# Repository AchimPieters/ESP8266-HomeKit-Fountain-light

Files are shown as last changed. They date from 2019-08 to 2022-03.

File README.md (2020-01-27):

# ESP8266-HomeKit-Fountain-light
ESP8266 – HomeKit Fountain light

For More Information Visit http://www.studiopieters.nl/

- [x] Make a new NeoPixel Ring
- [x] Beta Testing Software
- [x] Make A PCB
- [x] Ordering PCB Parts
- [x] Beta Testing PCB
- [x] Hardware Installation
- [x] Make POC Movie
- [x] Make end result Movie
- [x] Release KiCad files
- [x] Release gerber files

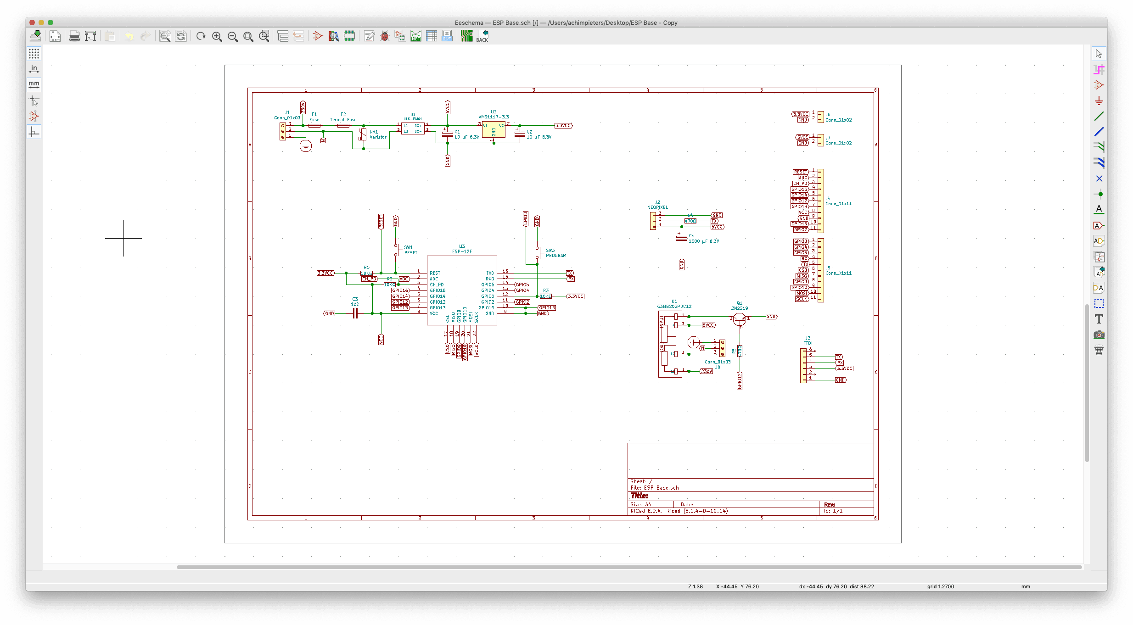
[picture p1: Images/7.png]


 




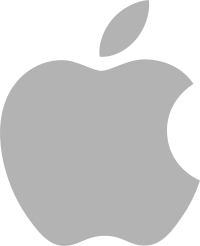
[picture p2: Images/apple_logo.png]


###### HomeKit Accessory Protocol (HAP) is Apple’s proprietary protocol that enables third-party accessories in the home (e.g., lights, thermostats and door locks) and Apple products to communicate with each other. HAP supports two transports, IP and Bluetooth LE. The information provided in the HomeKit Accessory Protocol Specification (Non-Commercial Version) describes how to implement HAP in an accessory that you create for non-commercial use and that will not be distributed or sold.

###### The HomeKit Accessory Protocol Specification (Non-Commercial Version) can be downloaded from the [HomeKit Apple Developer page.](https://developer.apple.com/homekit/)

###### Copyright © 2019 Apple Inc. All rights reserved.

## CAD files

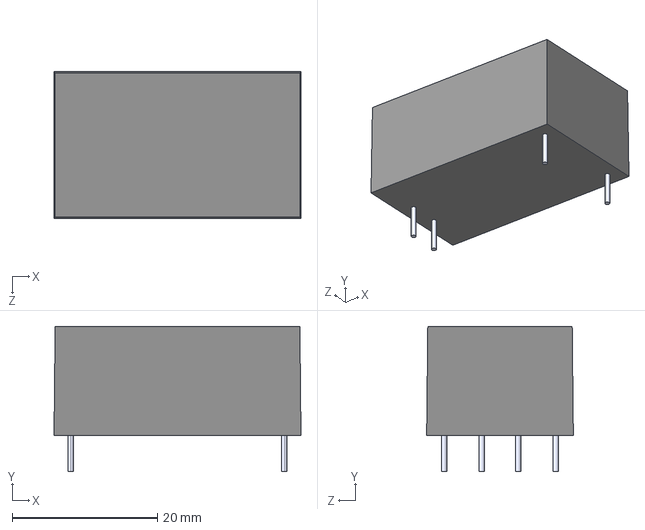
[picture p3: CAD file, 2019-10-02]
KiCad/HLK-PMXX/3D/Power_Supplies/AC_DC_Converters/STEP/HiLink_HLK-PM03.STEP
34.0 x 20.0 x 20.2 mm

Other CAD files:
KiCad/HLK-PMXX/3D/Power_Supplies/AC_DC_Converters/CAD/HiLink_HLK-PM03.SLDPRT

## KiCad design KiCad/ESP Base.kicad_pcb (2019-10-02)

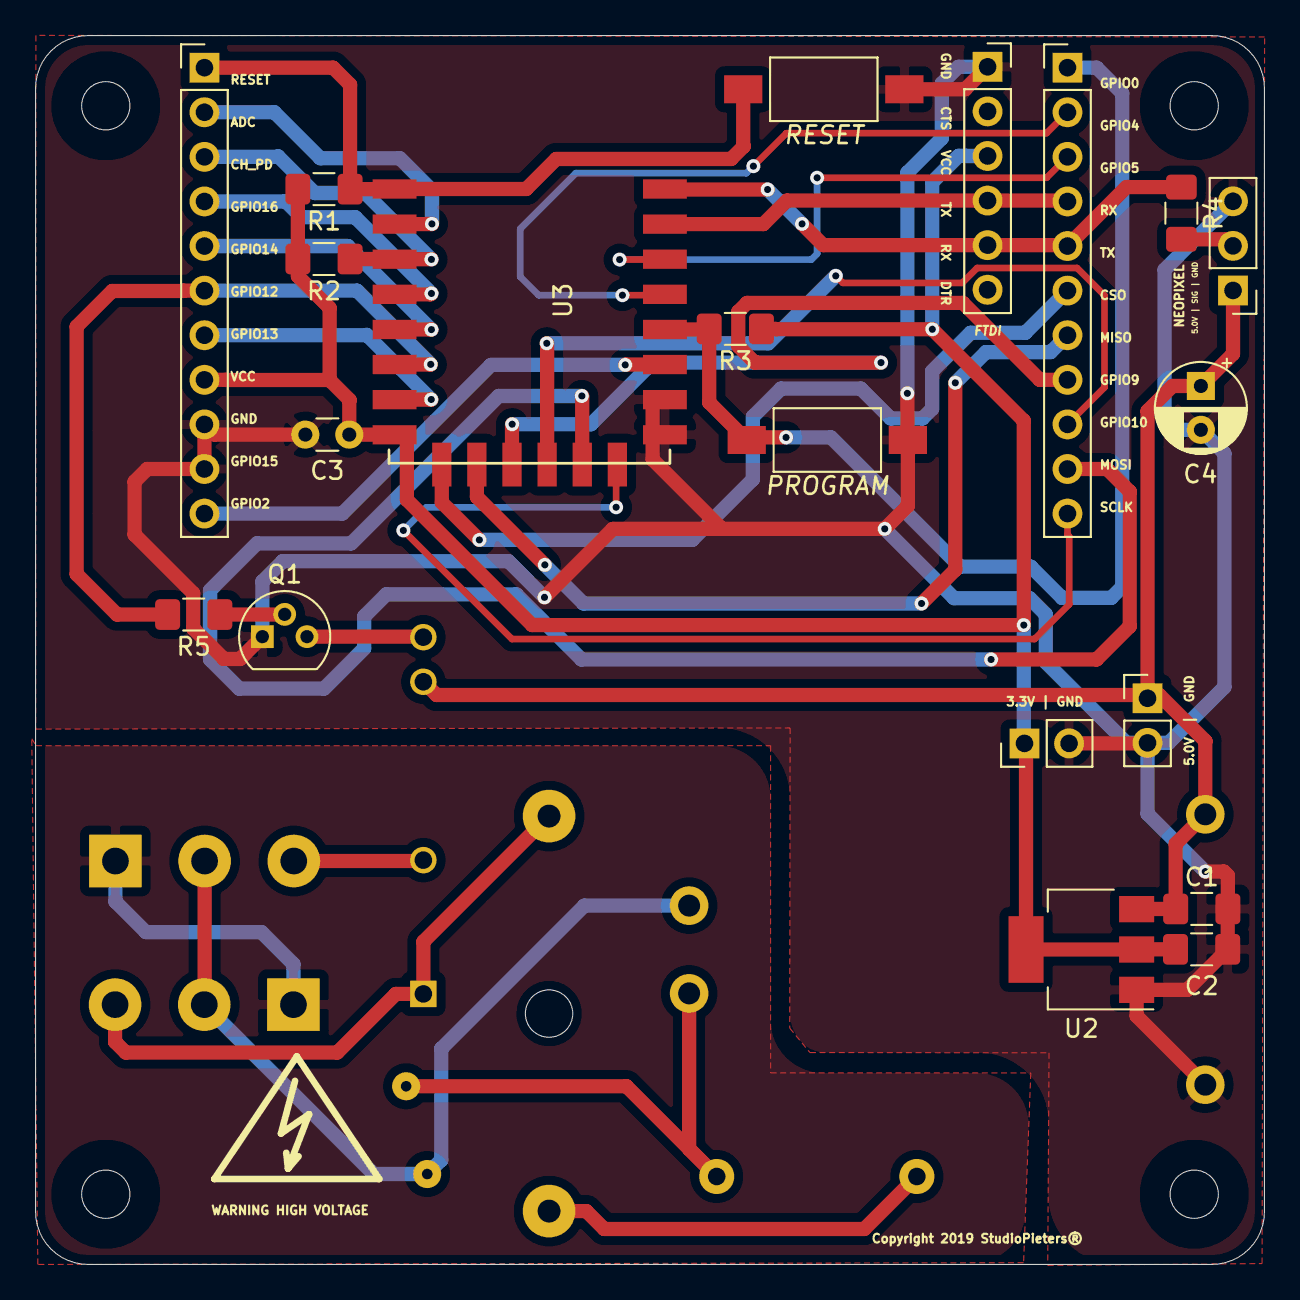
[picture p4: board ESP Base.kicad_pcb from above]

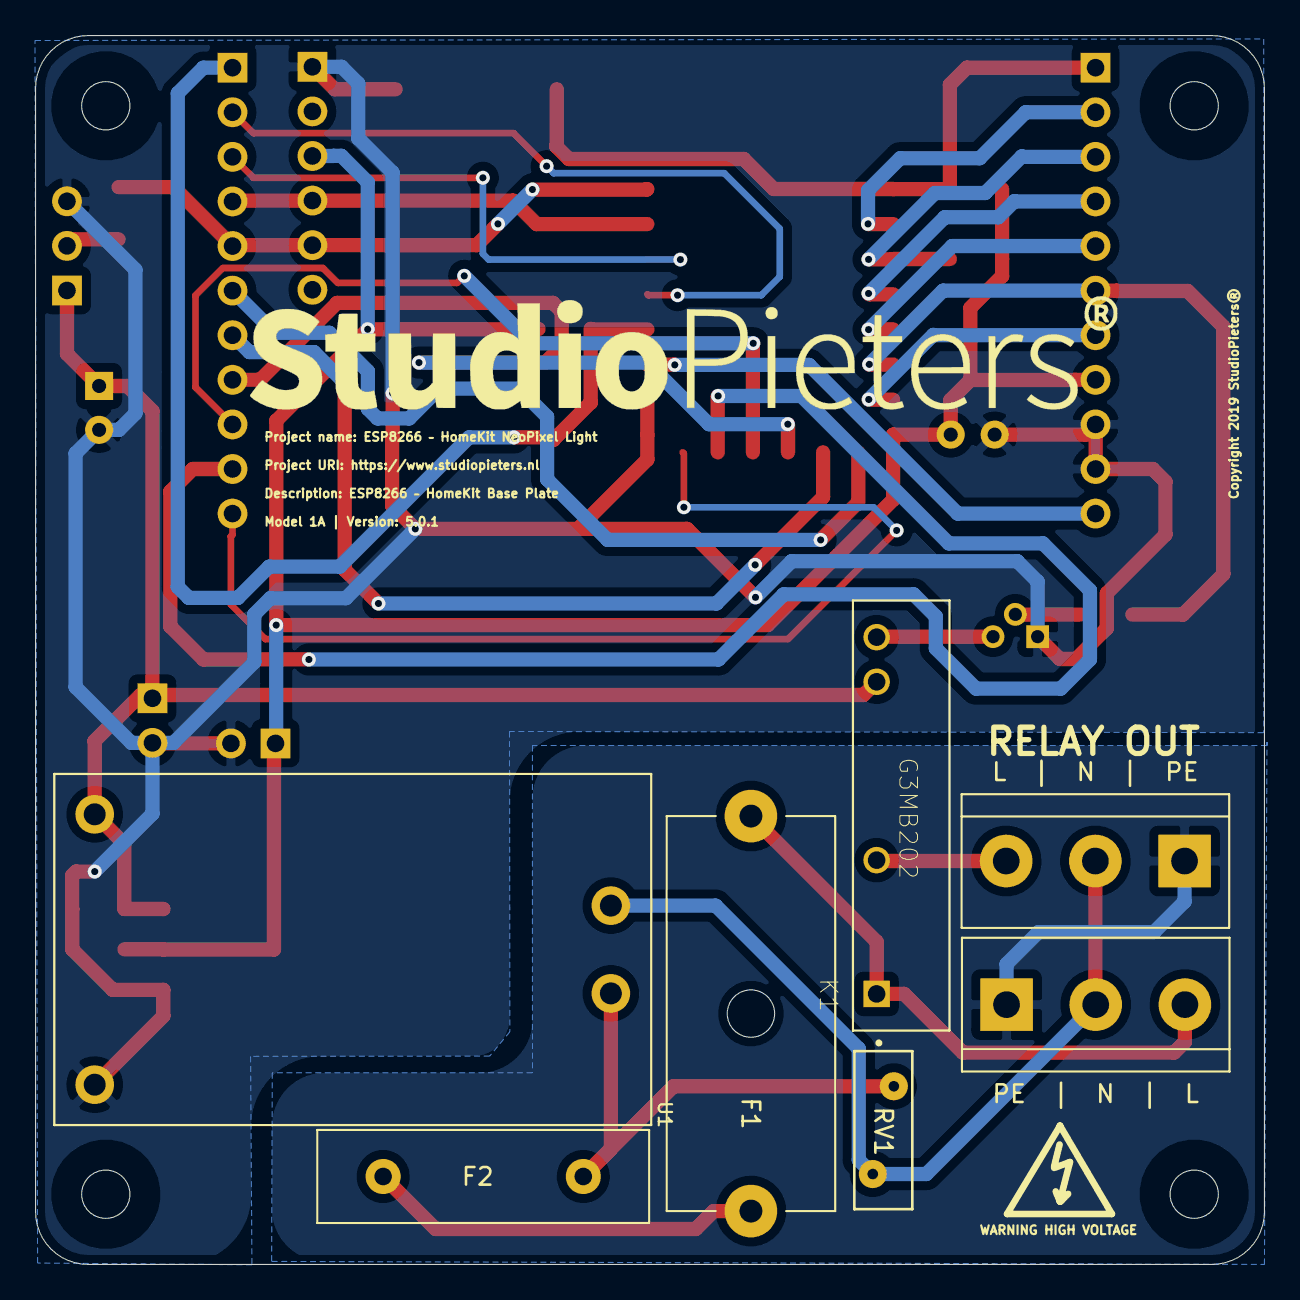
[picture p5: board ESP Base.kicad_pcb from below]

Board: 2 copper layers, 70.0 x 70.0 mm, 27 parts (7 on the bottom side), 31 nets.

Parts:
3.3V | GND, 5.0V  |  GND: Conn_01x02; PinHeader_1x02_P2.54mm_Vertical
C1, C2: 10 μF 6,3V; C_1206_3216Metric_Pad1.42x1.75mm_HandSolder
C3: 102; C_Disc_D3.0mm_W1.6mm_P2.50mm
C4: 1000 µF 6.3V; CP_Radial_D5.0mm_P2.50mm
F1: Fuse; Fuseholder_Cylinder-5x20mm_Schurter_0031_8201_Horizontal_Op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
F2: Termal Fuse; Fuse_Littelfuse-LVR100
J1: PE | N | L; TerminalBlock_bornier-3_P5.08mm
J2: NEOPIXEL; PinHeader_1x03_P2.54mm_Vertical
J3: FTDI; PinSocket_1x06_P2.54mm_Vertical
J4, J5: Conn_01x11; PinHeader_1x11_P2.54mm_Vertical
J8: L | N | PE; TerminalBlock_bornier-3_P5.08mm
K1: G3MB202; RELAY_G3MB202PDC12
PROGRAM: PROGRAM; SW_SPST_FSMSM
Q1: 2N2219; TO-92
R1, R2, R3: 10KΩ; R_1206_3216Metric_Pad1.42x1.75mm_HandSolder
R4, R5: 470Ω; R_1206_3216Metric_Pad1.42x1.75mm_HandSolder
RESET: RESET; SW_SPST_FSMSM
RV1: Varistor; RV_Disc_D9mm_W3.3mm_P5mm
U1: HLK-PM01
U2: AMS1117-3.3; SOT-223-3_TabPin2
U3: ESP-12F; ESP-12E_SMD

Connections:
3.3VCC: 3.3V | GND.1, C2.1, C3.1, J3.3, J4.8, R1.2, R2.2, R3.1, U2.2, U3.8
5VCC: 5.0V | GND.1, C1.1, C4.1, J2.1, K1.3, U1.4, U2.3
230V: F1.2, J1.3, K1.1
ADC: J4.2, U3.2
CH_PD: J4.3, R2.1, U3.3
CS0: J5.6, U3.17
Earth_Protective: J1.1, J8.1
GND: 3.3V | GND.2, 5.0V | GND.2, C1.2, C2.2, C3.2, C4.2, J2.3, J3.1, J4.9, J4.10, PROGRAM.1, Q1.1, RESET.1, U1.3, U2.1, U3.9, U3.10
GPIO0: J5.1, PROGRAM.2, R3.2, U3.12
GPIO2: J4.11, U3.11
GPIO4: J5.2, U3.13
GPIO5: J5.3, U3.14
GPIO9: J5.8, U3.19
GPIO10: J5.9, U3.20
GPIO12: J4.6, R5.2, U3.6
GPIO13: J4.7, U3.7
GPIO14: J4.5, U3.5
GPIO16: J4.4, U3.4
MISO: J5.7, U3.18
MOSI: J5.10, U3.21
N: J1.2, J8.2, RV1.2, U1.2
unnamed: F1.1, F2.2
unnamed: F2.1, RV1.1, U1.1
unnamed: J2.2, R4.2
unnamed: J8.3, K1.2
unnamed: K1.4, Q1.3
unnamed: Q1.2, R5.1
RESET: J4.1, R1.1, RESET.2, U3.1
RX: J3.4, J5.4, U3.15
SCLK: J5.11, U3.22
TX: J3.5, J5.5, R4.1, U3.16

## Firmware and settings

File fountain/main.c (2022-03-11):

/**

   Copyright 2022 Achim Pieters | StudioPieters®

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
   Build upon: ESP-HomeKit - MIT License - Copyright (c) 2017 Maxim Kulkin

 **/

#include <stdio.h>
#include <stdlib.h>
#include <espressif/esp_common.h>
#include <esp/uart.h>
#include <esp8266.h>
#include <FreeRTOS.h>
#include <task.h>
#include <math.h>

#include <homekit/homekit.h>
#include <homekit/characteristics.h>
#include "characteristic_types.h"
#include "software_versioning.h"
#include <wifi_config.h>

#include <ws2812_i2s/ws2812_i2s.h>
#include <button.h>

#define BUTTON_GPIO 4
#define RELAY_GPIO 12
#define LED_ON 0     // this is the value to write to GPIO for led on (0 = GPIO low)
#define LED_INBUILT_GPIO 2      // this is the onboard LED used to show on/off only
#define LED_COUNT 16    // this is the number of WS2812B leds on the strip
#define LED_RGB_SCALE 255       // this is the scaling factor used for color conversion

// Global variables
float led_hue = 0;      // hue is scaled 0 to 360
float led_saturation = 50;      // saturation is scaled 0 to 100
float led_brightness = 100;     // brightness is scaled 0 to 100
bool led_on = false;    // on is boolean on or off
ws2812_pixel_t pixels[LED_COUNT];

//http://blog.saikoled.com/post/44677718712/how-to-convert-from-hsi-to-rgb-white
static void hsi2rgb(float h, float s, float i, ws2812_pixel_t* rgb) {
        int r, g, b;

        while (h < 0) { h += 360.0F; }; // cycle h around to 0-360 degrees
        while (h >= 360) { h -= 360.0F; };
        h = 3.14159F*h / 180.0F;// convert to radians.
        s /= 100.0F; // from percentage to ratio
        i /= 100.0F; // from percentage to ratio
        s = s > 0 ? (s < 1 ? s : 1) : 0; // clamp s and i to interval [0,1]
        i = i > 0 ? (i < 1 ? i : 1) : 0; // clamp s and i to interval [0,1]
        i = i * sqrt(i);// shape intensity to have finer granularity near 0

        if (h < 2.09439) {
                r = LED_RGB_SCALE * i / 3 * (1 + s * cos(h) / cos(1.047196667 - h));
                g = LED_RGB_SCALE * i / 3 * (1 + s * (1 - cos(h) / cos(1.047196667 - h)));
                b = LED_RGB_SCALE * i / 3 * (1 - s);
        }
        else if (h < 4.188787) {
                h = h - 2.09439;
                g = LED_RGB_SCALE * i / 3 * (1 + s * cos(h) / cos(1.047196667 - h));
                b = LED_RGB_SCALE * i / 3 * (1 + s * (1 - cos(h) / cos(1.047196667 - h)));
                r = LED_RGB_SCALE * i / 3 * (1 - s);
        }
        else {
                h = h - 4.188787;
                b = LED_RGB_SCALE * i / 3 * (1 + s * cos(h) / cos(1.047196667 - h));
                r = LED_RGB_SCALE * i / 3 * (1 + s * (1 - cos(h) / cos(1.047196667 - h)));
                g = LED_RGB_SCALE * i / 3 * (1 - s);
        }

        rgb->red = (uint8_t) r;
        rgb->green = (uint8_t) g;
        rgb->blue = (uint8_t) b;
        rgb->white = (uint8_t) 0; // white channel is not used
}

void led_string_fill(ws2812_pixel_t rgb) {
// write out the new color to each pixel
        for (int i = 0; i < LED_COUNT; i++) {
                pixels[i] = rgb;
        }
        ws2812_i2s_update(pixels, PIXEL_RGB);
}

void led_string_set(void) {
        ws2812_pixel_t rgb = { { 0, 0, 0, 0 } };

        if (led_on) {
// convert HSI to RGBW
                hsi2rgb(led_hue, led_saturation, led_brightness, &rgb);
// set the inbuilt led
                gpio_write(LED_INBUILT_GPIO, LED_ON);
        }
        else {
                gpio_write(LED_INBUILT_GPIO, 1 - LED_ON);
        }
// write out the new color
        led_string_fill(rgb);
}

void led_init() {
// initialise the onboard led as a secondary indicator (handy for testing)
        gpio_enable(LED_INBUILT_GPIO, GPIO_OUTPUT);
// initialise the LED strip
        ws2812_i2s_init(LED_COUNT, PIXEL_RGB);
// set the initial state
        led_string_set();
}

void led_identify_task(void *_args) {
        const ws2812_pixel_t COLOR_PINK = { { 255, 0, 127, 0 } };
        const ws2812_pixel_t COLOR_BLACK = { { 0, 0, 0, 0 } };

        for (int i = 0; i < 3; i++) {
                for (int j = 0; j < 3; j++) {
                        gpio_write(LED_INBUILT_GPIO, LED_ON);
                        led_string_fill(COLOR_PINK);
                        vTaskDelay(100 / portTICK_PERIOD_MS);
                        gpio_write(LED_INBUILT_GPIO, 1 - LED_ON);
                        led_string_fill(COLOR_BLACK);
                        vTaskDelay(100 / portTICK_PERIOD_MS);
                }
                vTaskDelay(250 / portTICK_PERIOD_MS);
        }

        led_string_set();
        vTaskDelete(NULL);
}

void led_identify(homekit_value_t _value) {
        xTaskCreate(led_identify_task, "LED identify", 128, NULL, 2, NULL);
}

homekit_value_t led_on_get() {
        return HOMEKIT_BOOL(led_on);
}

void led_on_set(homekit_value_t value) {
        if (value.format != homekit_format_bool) {
                return;
        }

        led_on = value.bool_value;
        led_string_set();
}

homekit_value_t led_brightness_get() {
        return HOMEKIT_INT(led_brightness);
}
void led_brightness_set(homekit_value_t value) {
        if (value.format != homekit_format_int) {
                return;
        }
        led_brightness = value.int_value;
        led_string_set();
}

homekit_value_t led_hue_get() {
        return HOMEKIT_FLOAT(led_hue);
}

void led_hue_set(homekit_value_t value) {
        if (value.format != homekit_format_float) {
                return;
        }
        led_hue = value.float_value;
        led_string_set();
}

homekit_value_t led_saturation_get() {
        return HOMEKIT_FLOAT(led_saturation);
}

void led_saturation_set(homekit_value_t value) {
        if (value.format != homekit_format_float) {
                return;
        }
        led_saturation = value.float_value;
        led_string_set();
}


void switch_on_callback(homekit_characteristic_t *_ch, homekit_value_t on, void *context);
void button_callback(button_event_t event, void* context);

void relay_write(bool on) {
        gpio_write( RELAY_GPIO, on ? 1 : 0);
}

homekit_characteristic_t switch_on = HOMEKIT_CHARACTERISTIC_(
        ON, false, .callback=HOMEKIT_CHARACTERISTIC_CALLBACK(switch_on_callback)
        );

void gpio_init() {
        gpio_enable( RELAY_GPIO, GPIO_OUTPUT);
        relay_write(switch_on.value.bool_value);
}

void switch_on_callback(homekit_characteristic_t *_ch, homekit_value_t on, void *context) {
        relay_write(switch_on.value.bool_value);
}

void button_callback(button_event_t event, void* context) {
        switch (event) {
        case button_event_single_press:
                printf("Toggling relay\n");
                switch_on.value.bool_value = !switch_on.value.bool_value;
                relay_write(switch_on.value.bool_value);
                homekit_characteristic_notify(&switch_on, switch_on.value);
                break;
        case button_event_long_press:
                break;
        default:
                printf("Unknown button event: %d\n", event);
        }
}

#define DEVICE_NAME "WATER FOUNTAIN"
#define DEVICE_MANUFACTURER "StudioPieters®"
// See Naming convention.md
#define DEVICE_SERIAL "NLDA4SQN1466"
// See Naming convention.md
#define DEVICE_MODEL "SD466NL/A"
// Will get his version numer trough software_versioning
#define FW_VERSION "0.0.0"

homekit_characteristic_t ota_trigger = API_OTA_TRIGGER;
homekit_characteristic_t name = HOMEKIT_CHARACTERISTIC_(NAME, DEVICE_NAME);
homekit_characteristic_t manufacturer = HOMEKIT_CHARACTERISTIC_(MANUFACTURER,  DEVICE_MANUFACTURER);
homekit_characteristic_t serial = HOMEKIT_CHARACTERISTIC_(SERIAL_NUMBER, DEVICE_SERIAL);
homekit_characteristic_t model= HOMEKIT_CHARACTERISTIC_(MODEL, DEVICE_MODEL);
homekit_characteristic_t revision = HOMEKIT_CHARACTERISTIC_(FIRMWARE_REVISION,  FW_VERSION);

homekit_accessory_t *accessories[] = {
        HOMEKIT_ACCESSORY(.id = 1, .category = homekit_accessory_category_lightbulb, .services = (homekit_service_t*[]) {
                HOMEKIT_SERVICE(ACCESSORY_INFORMATION, .characteristics = (homekit_characteristic_t*[]) {
                        &name,
                        &manufacturer,
                        &serial,
                        &model,
                        &revision,
                        HOMEKIT_CHARACTERISTIC(IDENTIFY, led_identify),
                        NULL
                }),
                HOMEKIT_SERVICE(LIGHTBULB, .primary = true, .characteristics = (homekit_characteristic_t*[]) {
                        HOMEKIT_CHARACTERISTIC(NAME, "NEOPIXEL RING"),

                        HOMEKIT_CHARACTERISTIC(
                                ON, true,
                                .getter = led_on_get,
                                .setter = led_on_set
                                ),
                        HOMEKIT_CHARACTERISTIC(
                                BRIGHTNESS, 100,
                                .getter = led_brightness_get,
                                .setter = led_brightness_set
                                ),
                        HOMEKIT_CHARACTERISTIC(
                                HUE, 0,
                                .getter = led_hue_get,
                                .setter = led_hue_set
                                ),
                        HOMEKIT_CHARACTERISTIC(
                                SATURATION, 0,
                                .getter = led_saturation_get,
                                .setter = led_saturation_set
                                ),
                        NULL
                }),
                HOMEKIT_SERVICE(SWITCH, .characteristics=(homekit_characteristic_t*[]) {
                        HOMEKIT_CHARACTERISTIC(NAME, "WATER PUMP"),
                        &switch_on,
                        &ota_trigger,
                        NULL
                }),
                NULL
        }),
        NULL
};

void on_event(homekit_event_t event) {

}

// tools/gen_qrcode 5 252-87-678 4G4J qrcode.png
homekit_server_config_t config = {
        .accessories = accessories,
        .password = "252-87-678",
        .setupId= "4G4J",
        .on_event = on_event,
};

void create_accessory_name() {
        int serialLength = snprintf(NULL, 0, "%d", sdk_system_get_chip_id());
        char *serialNumberValue = malloc(serialLength + 1);
        snprintf(serialNumberValue, serialLength + 1, "%d", sdk_system_get_chip_id());
        int name_len = snprintf(NULL, 0, "%s-%s", DEVICE_NAME, serialNumberValue);
        if (name_len > 63) { name_len = 63; }
        char *name_value = malloc(name_len + 1);
        snprintf(name_value, name_len + 1, "%s-%s", DEVICE_NAME, serialNumberValue);
        name.value = HOMEKIT_STRING(name_value);
}

void on_wifi_ready(){

}

void user_init(void) {
        uart_set_baud(0, 115200);
        homekit_server_init(&config);
        led_init();
        gpio_init();

// Get Github version number
        int c_hash=ota_read_sysparam(&revision.value.string_value);
        config.accessories[0]->config_number=c_hash;

        button_config_t config = BUTTON_CONFIG(
                button_active_low,
                .long_press_time = 4000,
                .max_repeat_presses = 3,
                );

        int b = button_create(BUTTON_GPIO, config, button_callback, NULL);
        if (b) {
                printf("Failed to initialize a button\n");
        }
}

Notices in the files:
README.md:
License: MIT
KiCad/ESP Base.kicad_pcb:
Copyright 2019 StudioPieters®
